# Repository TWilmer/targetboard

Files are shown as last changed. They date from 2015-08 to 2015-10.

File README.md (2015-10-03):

Targetboard

Warning1: v1 of the board has a bug in the VDD/VSS connection of the CAN drivers. To fix the board lift the power supply pins of the can transceiver chips
Warning2: v1 of the board has a bug in IR receiver footprint pin 1 and 3 are mixed up
Warning3: v1 of the board has the USB connector too near to the Serial Port

What works:
- IR sender
- Leds
- Button
- Serial Port 3
- WIFI port (no SW support yet)
- JTAG, I'm using a recent openocd on RPi B+

this is my hobby project. It supports a lot of features where I want me an my daughter to play with:
- Simulate a Traffic light
- USB to Serial communication
- USB to CAN-Bus (High-Speed only), you need a second board to make some use
- 4 motor drivers
- JTAG probe

The software part is released under GPL2 additionally you have to follow
the original Software's license - e.g. the firmware may be used only
for LPC parts. To compile you need also to install the LPCopen deliver for LPC1769 devices.

The CAD Files are released under GPL2, too. It contains a ZIP
file, which can be used to oder the PCB and if you want also assembly
from SeedStudio - including a proper BOM list.

http://www.seeedstudio.com/service/index.php?r=pcb

So far I have not received any Assembled PCB - so everything is at
your own risk.

This board will use a LPC1768 - as this is availble at SeedStudio, but a LPC1769 should work, too.  A higher clock frequency is possible with LPC1769, but I don't plan to use it.

A set of two assembled board cost around 140$, where you get 3 blank PCBs extra. As SeedStudio is assemblying manually - it should be possible to populate this board also manually.

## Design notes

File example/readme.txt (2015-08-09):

Based on the USB to UART bridge example

dfu-util -d 0x471:0xdf55 -c 0 -t 2048 -R -D /usr/local/lpcxpresso_7.5.0_254/lpcxpresso/bin/LPCXpressoWIN.enc
dfu-util -d 0x471:0xdf55 -c 0 -t 2048 -R -D  /usr/local/lpcxpresso_7.7.2_379/lpcxpresso/bin/LPCXpressoWIN.enc
This program is for the lpcexpresso Board. To be connected:

up to two can transceiver:
 - P0.4 and P0.5
 - P0.1 and P0.2
 
 one USB to Serial Converter at UART 0 - may also be used for intial programming i
  - P0.2 and P0.3 for programming P2.10 has to be low
  - P0.15 P0.16 as a connection to the Target
  
  We have up to 16 endpoints, this means we can make use of them:
   2 - UART to UART0
   2 - UART UART2 to Target
   2 - CAN0
   2 - CAN1

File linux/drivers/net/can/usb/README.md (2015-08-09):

CAN driver for LPC1769 Target board
================================================

Note
----
THIS SOFTWARE COMES WITHOUT ANY WARRANTY!

License
-------
GPL v2

How to build
------------
* Make sure you have kernel version >= 2.6.33 installed
* For pre-3.3 kernels, check out the pre-3.3 branch
* Install kernel header files and gcc
* Simple type "make"

DKMS integration
----------------
* Install the dkms package for your distro
* Check out the required branch from this repository
* Do a git archive --prefix=cantwi-1.0/ -o /usr/src/cantwi-1.0.tar HEAD
* Extract the archive in the /usr/src directory
* Add the module, e.g. with dkms add -m cantwi -v 1.0 --verbose
* Build the module, e.g. with dkms build -m cantwi -v 1.0 --verbose
* Install the module, e.g. with dkms install -m cantwi -v 1.0 --verbose
* You can also build packages for your distro, see man dkms

Set up interface
----------------
    modprobe can_raw
    modprobe can_dev
    insmod can_twi.ko
    ip link set can0 up type can bitrate 1000000 sample-point 0.875

Shut down interface
-------------------
    ip link set can0 down
    rmmod can_twi

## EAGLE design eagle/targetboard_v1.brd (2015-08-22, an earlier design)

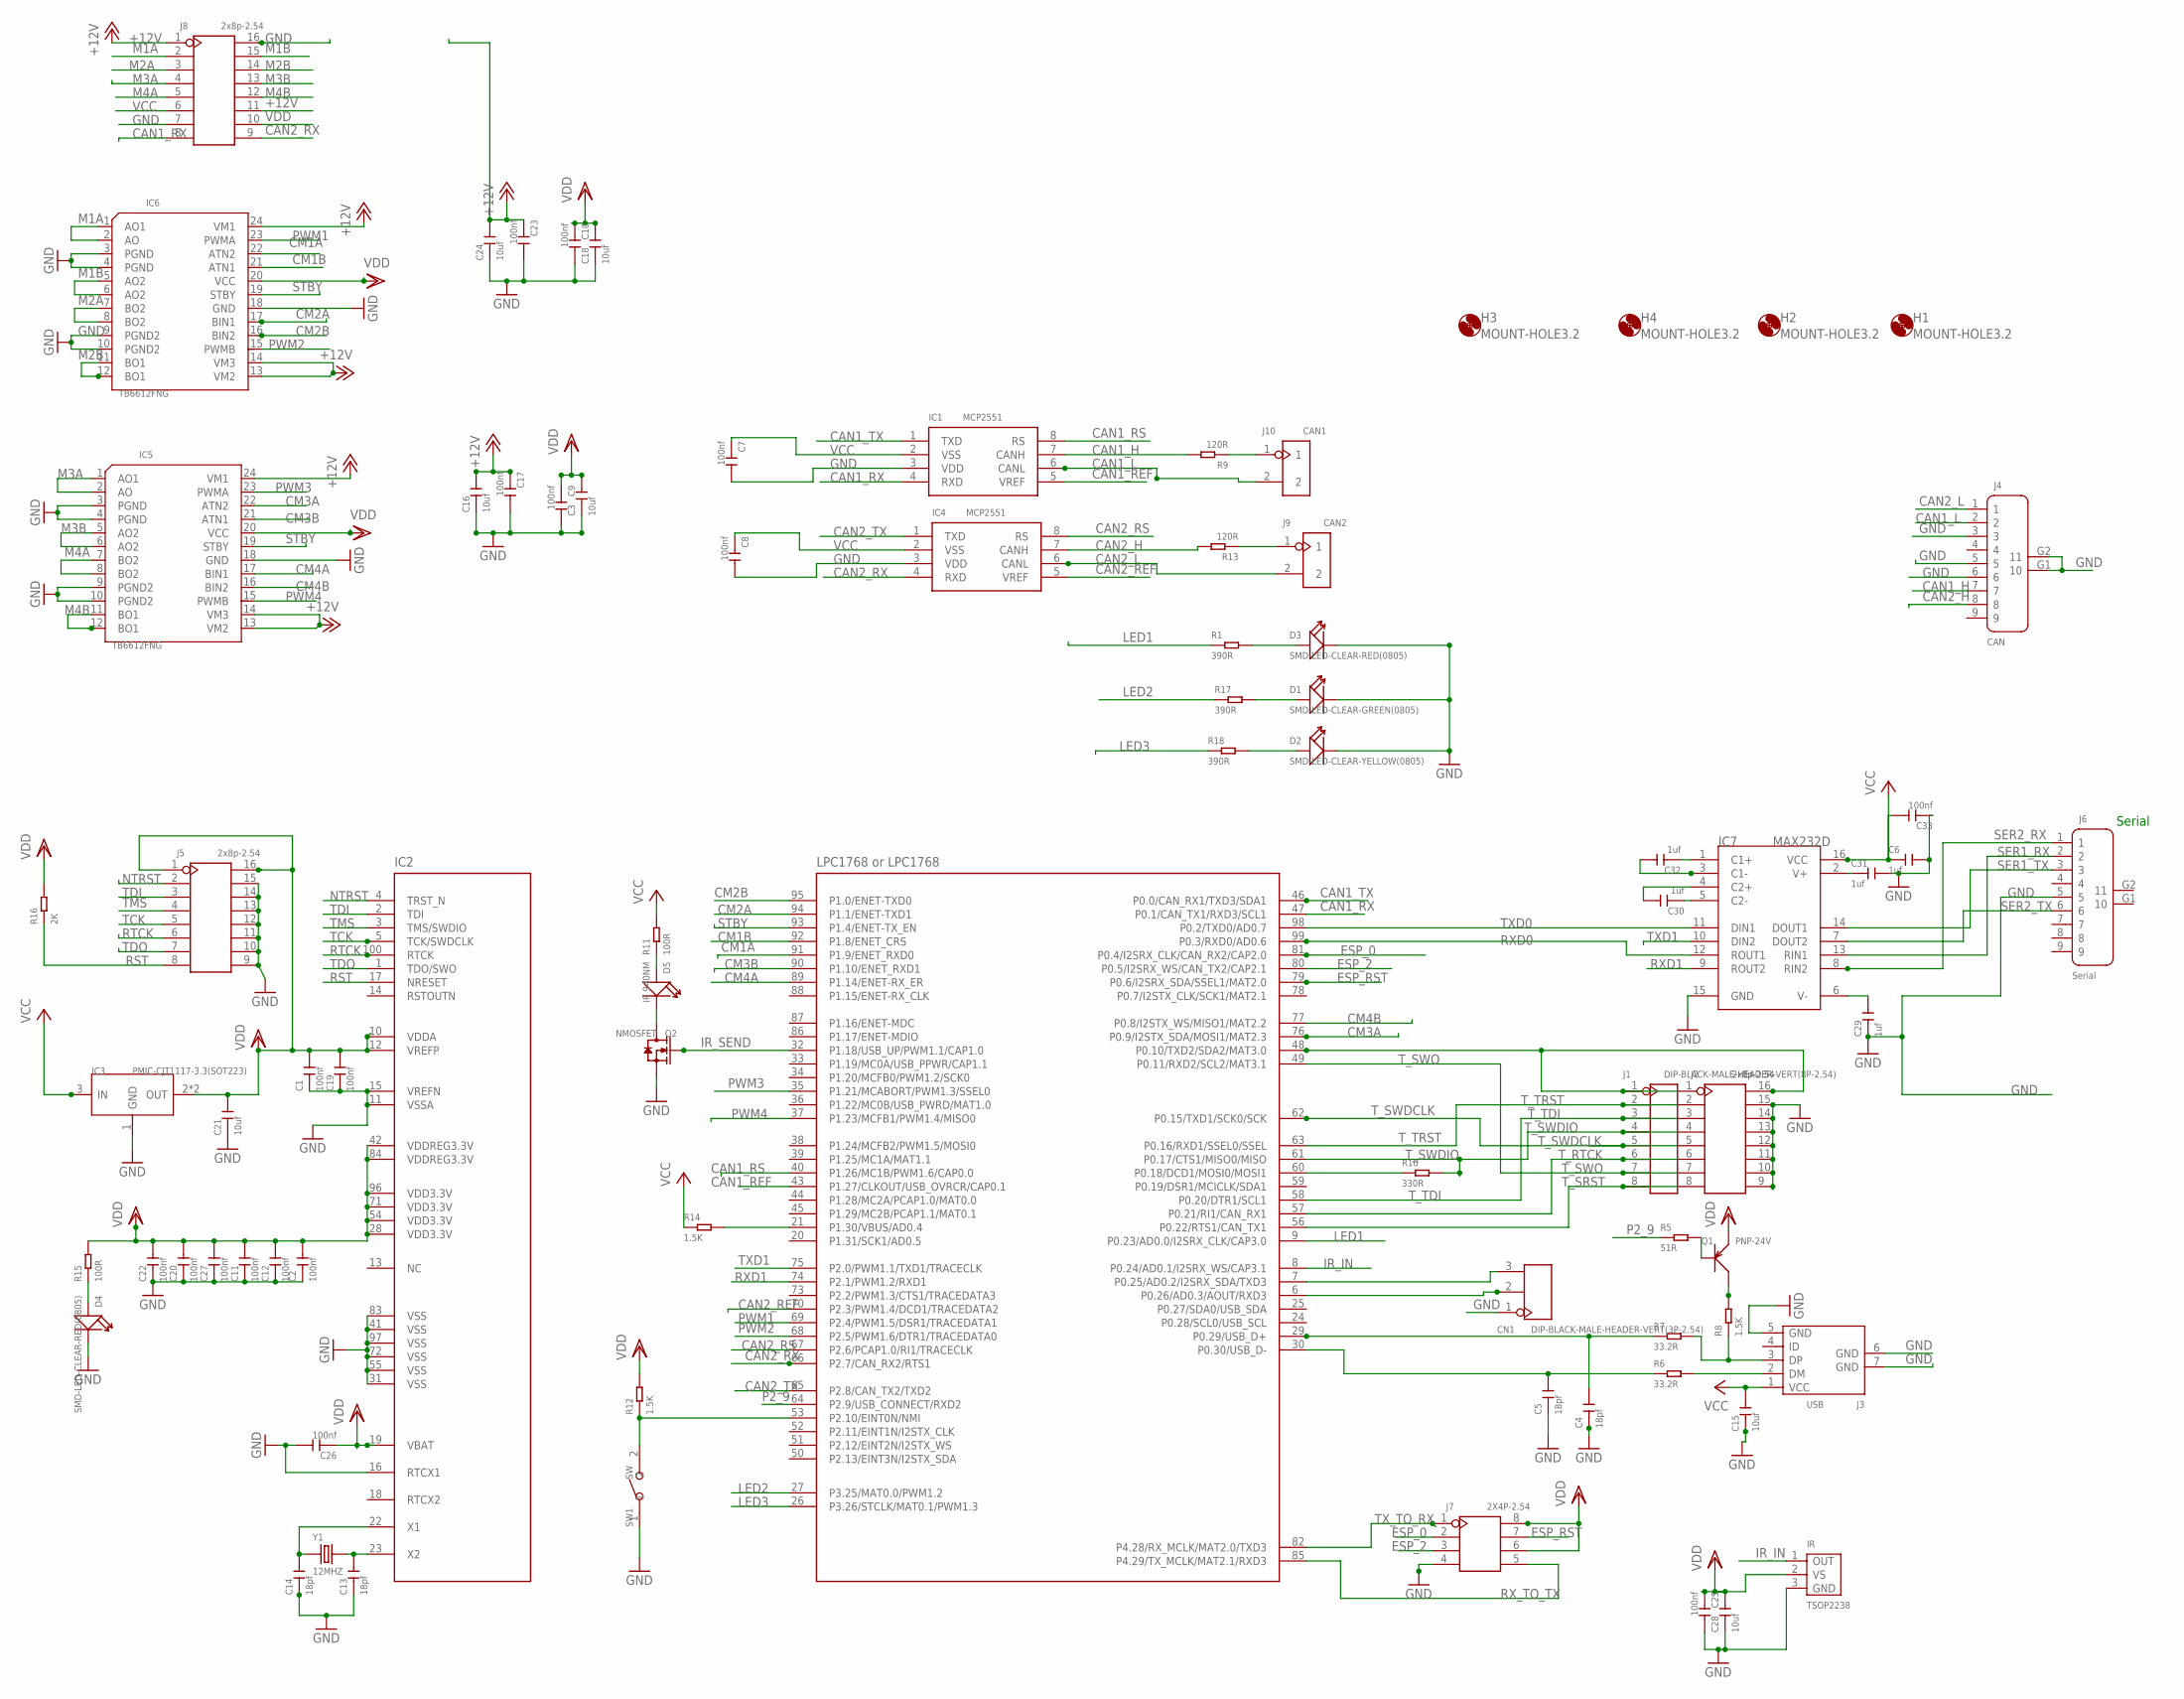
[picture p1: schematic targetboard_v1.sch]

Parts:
C1, C2, C7, C8, C9, C10, C11, C12, C17, C19, C20, C22, C23, C25, C26, C27, C33: 100nf; C0805
C3, C16, C18, C21, C24, C28: 10uf; C0805
C4, C5, C13, C14: 18pf; C0805
C6, C29, C30, C31, C32: 1uf; C0805
C15: 10uf; C0603
CN1: DIP-BLACK-MALE-HEADER-VERT(3P-2.54); H3-2.54
D1: SMD-LED-CLEAR-GREEN(0805); LED-0805
D2: SMD-LED-CLEAR-YELLOW(0805); LED-0805
D3, D4: SMD-LED-CLEAR-RED(0805); LED-0805
D5: IR 940NM; LED2-2.54-D5.0MM
H1, H2, H3, H4: MOUNT-HOLE3.2; 3,2
IC1, IC4: MCP2551; SOIC8-1.27-5X4MM
IC2: LPC1768 or LPC1768; LQFP100-0.5-13.8X13.8MM
IC3: PMIC-CJT1117-3.3(SOT223); SOT-223
IC5, IC6: TB6612FNG; SSOP24-0.65-8.9X5.3MM
IC7: MAX232D; SOIC16-1.27-10X3.9MM
IR: TSOP2238; SNR3-2.54-6.95X6.0X5.6MM
J1: DIP-BLACK-MALE-HEADER-VERT(8P-2.54); H8-2.54
J2, J5, J8: 2x8p-2.54; H2X8-2.54
J3: USB; MICRO-USB5+2P-SMD-0.65
J4: CAN; DSUB9+2P-2.77-90D-MALE
J6: Serial; DSUB9+2P-2.77-90D-MALE
J7: 2X4P-2.54; H2X4-2.54
J9: CAN2; H2-2.54
J10: CAN1; H2-2.54
Q1: PNP-24V; SOT-23
Q2: NMOSFET; SOT-23
R1, R17, R18: 390R; R0805
R5: 51R; R0603
R6, R7: 33.2R; R0603
R8, R12, R14: 1.5K; R0805
R9, R13: 120R; R0805
R10: 330R; R0603
R11, R15: 100R; R0805
R16: 2K; R0805
SW1: SW; SW2-2.6-3.0X2.5X1.2+0.4MM
Y1: 12MHZ; X2-SMD-5.0X3.2X1.3MM

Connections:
+12V: C16.2, C17.1, C23.1, C24.2, IC5.13 (VM2), IC5.14 (VM3), IC5.24 (VM1), IC6.13 (VM2), IC6.14 (VM3), IC6.24 (VM1), J8.1, J8.11
CAN1_H: IC1.7 (CANH), J4.7, R9.2
CAN1_L: IC1.6 (CANL), J4.2, J10.2
CAN1_REF: IC1.5 (VREF), IC2.43 (P1.27/CLKOUT/USB_OVRCR/CAP0.1)
CAN1_RS: IC1.8 (RS), IC2.40 (P1.26/MC1B/PWM1.6/CAP0.0)
CAN1_RX: IC1.4 (RXD), IC2.47 (P0.1/CAN_TX1/RXD3/SCL1), J8.8
CAN1_TX: IC1.1 (TXD), IC2.46 (P0.0/CAN_RX1/TXD3/SDA1)
CAN2_H: IC4.7 (CANH), J4.8, R13.2
CAN2_L: IC4.6 (CANL), J4.1, J9.2
CAN2_REF: IC2.70 (P2.3/PWM1.4/DCD1/TRACEDATA2), IC4.5 (VREF)
CAN2_RS: IC2.67 (P2.6/PCAP1.0/RI1/TRACECLK), IC4.8 (RS)
CAN2_RX: IC2.66 (P2.7/CAN_RX2/RTS1), IC4.4 (RXD), J8.9
CAN2_TX: IC2.65 (P2.8/CAN_TX2/TXD2), IC4.1 (TXD)
CM1A: IC2.91 (P1.9/ENET_RXD0), IC6.22 (ATN2)
CM1B: IC2.92 (P1.8/ENET_CRS), IC6.21 (ATN1)
CM2A: IC2.94 (P1.1/ENET-TXD1), IC6.17 (BIN1)
CM2B: IC2.95 (P1.0/ENET-TXD0), IC6.16 (BIN2)
CM3A: IC2.76 (P0.9/I2STX_SDA/MOSI1/MAT2.3), IC5.22 (ATN2)
CM3B: IC2.90 (P1.10/ENET_RXD1), IC5.21 (ATN1)
CM4A: IC2.89 (P1.14/ENET-RX_ER), IC5.17 (BIN1)
CM4B: IC2.77 (P0.8/I2STX_WS/MISO1/MAT2.2), IC5.16 (BIN2)
DM: J3.2 (DM), R6.2
DP: J3.3 (DP), R7.2, R8.1
EDM: C5.2, IC2.30 (P0.30/USB_D-), R6.1
EDP: C4.2, IC2.29 (P0.29/USB_D+), R7.1
ESP_0: IC2.81 (P0.4/I2SRX_CLK/CAN_RX2/CAP2.0), J7.2
ESP_2: IC2.80 (P0.5/I2SRX_WS/CAN_TX2/CAP2.1), J7.3
ESP_RST: IC2.79 (P0.6/I2SRX_SDA/SSEL1/MAT2.0), J7.7
GND: C1.1, C2.1, C3.1, C4.1, C5.1, C6.2, C7.2, C8.2, C9.2, C10.2, C11.1, C12.1, C13.1, C14.1, C15.1, C16.1, C17.2, C18.1, C19.1, C20.1, C21.1, C22.1, C23.2, C24.1, C25.2, C26.2, C27.1, C28.1, C29.1, C31.2, C33.1, CN1.1, D1.-, D2.-, D3.-, D4.-, IC1.3 (VDD), IC2.11 (VSSA), IC2.15 (VREFN), IC2.16 (RTCX1), IC2.31 (VSS), IC2.41 (VSS), IC2.55 (VSS), IC2.72 (VSS), IC2.83 (VSS), IC2.97 (VSS), IC3.1 (GND), IC4.3 (VDD), IC5.3 (PGND), IC5.4 (PGND), IC5.9 (PGND2), IC5.10 (PGND2), IC5.18 (GND), IC6.3 (PGND), IC6.4 (PGND), IC6.9 (PGND2), IC6.10 (PGND2), IC6.18 (GND), IC7.15 (GND), IR.3 (GND), J2.9, J2.10, J2.11, J2.12, J2.13, J2.14, J2.15, J3.5 (GND), J3.6 (GND), J3.7 (GND), J4.3, J4.5, J4.6, J4.G1 (10), J4.G2 (11), J5.9, J5.10, J5.11, J5.12, J5.13, J5.14, J5.15, J6.5, J7.4, J8.7, J8.16, Q2.2 (S), SW1.1
IR_IN: IC2.8 (P0.24/AD0.1/I2SRX_WS/CAP3.1), IR.1 (OUT)
IR_SEND: IC2.32 (P1.18/USB_UP/PWM1.1/CAP1.0), Q2.1 (G)
LED1: IC2.9 (P0.23/AD0.0/I2SRX_CLK/CAP3.0), R1.1
LED2: IC2.27 (P3.25/MAT0.0/PWM1.2), R17.1
LED3: IC2.26 (P3.26/STCLK/MAT0.1/PWM1.3), R18.1
M1A: IC6.1 (AO1), IC6.2 (AO), J8.2
M1B: IC6.5 (AO2), IC6.6 (AO2), J8.15
M2A: IC6.7 (BO2), IC6.8 (BO2), J8.3
M2B: IC6.11 (BO1), IC6.12 (BO1), J8.14
M3A: IC5.1 (AO1), IC5.2 (AO), J8.4
M3B: IC5.5 (AO2), IC5.6 (AO2), J8.13
M4A: IC5.7 (BO2), IC5.8 (BO2), J8.5
M4B: IC5.11 (BO1), IC5.12 (BO1), J8.12
unnamed: IC2.48 (P0.10/TXD2/SDA2/MAT3.0), J1.1, J2.1, J2.16
unnamed: IC2.53 (P2.10/EINT0N/NMI), R12.1, SW1.2
unnamed: D2.+, R18.2
unnamed: D1.+, R17.2
unnamed: D3.+, R1.2
unnamed: C14.2, IC2.22 (X1), Y1.1
unnamed: Q1.3 (C), R8.2
unnamed: C13.2, IC2.23 (X2), Y1.2
unnamed: Q1.1 (B), R5.2
unnamed: IC2.21 (P1.30/VBUS/AD0.4), R14.2
unnamed: J10.1, R9.1
unnamed: J9.1, R13.1
unnamed: D5.+, R11.1
unnamed: C30.2, IC7.4 (C2+)
unnamed: C30.1, IC7.5 (C2-)
unnamed: C32.1, IC7.1 (C1+)
unnamed: C32.2, IC7.3 (C1-)
unnamed: C29.2, IC7.6 (V-)
unnamed: C31.1, IC7.2 (V+)
unnamed: D5.-, Q2.3 (D)
unnamed: IC2.60 (P0.18/DCD1/MOSI0/MOSI1), R10.1
unnamed: D4.+, R15.1
NTRST: IC2.4 (TRST_N), J5.2
P2_9: IC2.64 (P2.9/USB_CONNECT/RXD2), R5.1
PWM1: IC2.69 (P2.4/PWM1.5/DSR1/TRACEDATA1), IC6.23 (PWMA)
PWM2: IC2.68 (P2.5/PWM1.6/DTR1/TRACEDATA0), IC6.15 (PWMB)
PWM3: IC2.35 (P1.21/MCABORT/PWM1.3/SSEL0), IC5.23 (PWMA)
PWM4: IC2.37 (P1.23/MCFB1/PWM1.4/MISO0), IC5.15 (PWMB)
RST: IC2.17 (NRESET), J5.8, R16.1
RTCK: IC2.100 (RTCK), J5.6
RX3: CN1.2, IC2.6 (P0.26/AD0.3/AOUT/RXD3)
RXD0: IC2.99 (P0.3/RXD0/AD0.6), IC7.12 (ROUT1)
RXD1: IC2.74 (P2.1/PWM1.2/RXD1), IC7.9 (ROUT2)
RX_TO_TX: IC2.85 (P4.29/TX_MCLK/MAT2.1/RXD3), J7.5
SER1_RX: IC7.13 (RIN1), J6.2
SER1_TX: IC7.14 (DOUT1), J6.3
SER2_RX: IC7.8 (RIN2), J6.1
SER2_TX: IC7.7 (DOUT2), J6.6
STBY: IC2.93 (P1.4/ENET-TX_EN), IC5.19 (STBY), IC6.19 (STBY)
TCK: IC2.5 (TCK/SWDCLK), J5.5
TDI: IC2.2 (TDI), J5.3
TDO: IC2.1 (TDO/SWO), J5.7
TMS: IC2.3 (TMS/SWDIO), J5.4
TX3: CN1.3, IC2.7 (P0.25/AD0.2/I2SRX_SDA/TXD3)
TXD0: IC2.98 (P0.2/TXD0/AD0.7), IC7.11 (DIN1)
TXD1: IC2.75 (P2.0/PWM1.1/TXD1/TRACECLK), IC7.10 (DIN2)
TX_TO_RX: IC2.82 (P4.28/RX_MCLK/MAT2.0/TXD3), J7.1
T_RTCK: IC2.57 (P0.21/RI1/CAN_RX1), J1.6, J2.6
T_SRST: IC2.56 (P0.22/RTS1/CAN_TX1), J1.8, J2.8
T_SWDCLK: IC2.62 (P0.15/TXD1/SCK0/SCK), J1.5, J2.5
T_SWDIO: IC2.61 (P0.17/CTS1/MISO0/MISO), J1.4, J2.4, R10.2
T_SWO: IC2.49 (P0.11/RXD2/SCL2/MAT3.1), J1.7, J2.7
T_TDI: IC2.58 (P0.20/DTR1/SCL1), J1.3, J2.3
T_TRST: IC2.63 (P0.16/RXD1/SSEL0/SSEL), J1.2, J2.2
VCC: C6.1, C7.1, C8.1, C15.2, C33.2, IC1.2 (VSS), IC3.3 (IN), IC4.2 (VSS), IC7.16 (VCC), J3.1 (VCC), J8.6, R11.2, R14.1
VDD: C1.2, C2.2, C3.2, C9.1, C10.1, C11.2, C12.2, C18.2, C19.2, C20.2, C21.2, C22.2, C25.1, C26.1, C27.2, C28.2, IC2.10 (VDDA), IC2.12 (VREFP), IC2.19 (VBAT), IC2.28 (VDD3.3V), IC2.42 (VDDREG3.3V), IC2.54 (VDD3.3V), IC2.71 (VDD3.3V), IC2.84 (VDDREG3.3V), IC2.96 (VDD3.3V), IC3.2 (OUT), IC3.TER (OUT), IC5.20 (VCC), IC6.20 (VCC), IR.2 (VS), J5.1, J5.16, J7.6, J7.8, J8.10, Q1.2 (E), R12.2, R15.2, R16.2

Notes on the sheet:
Serial

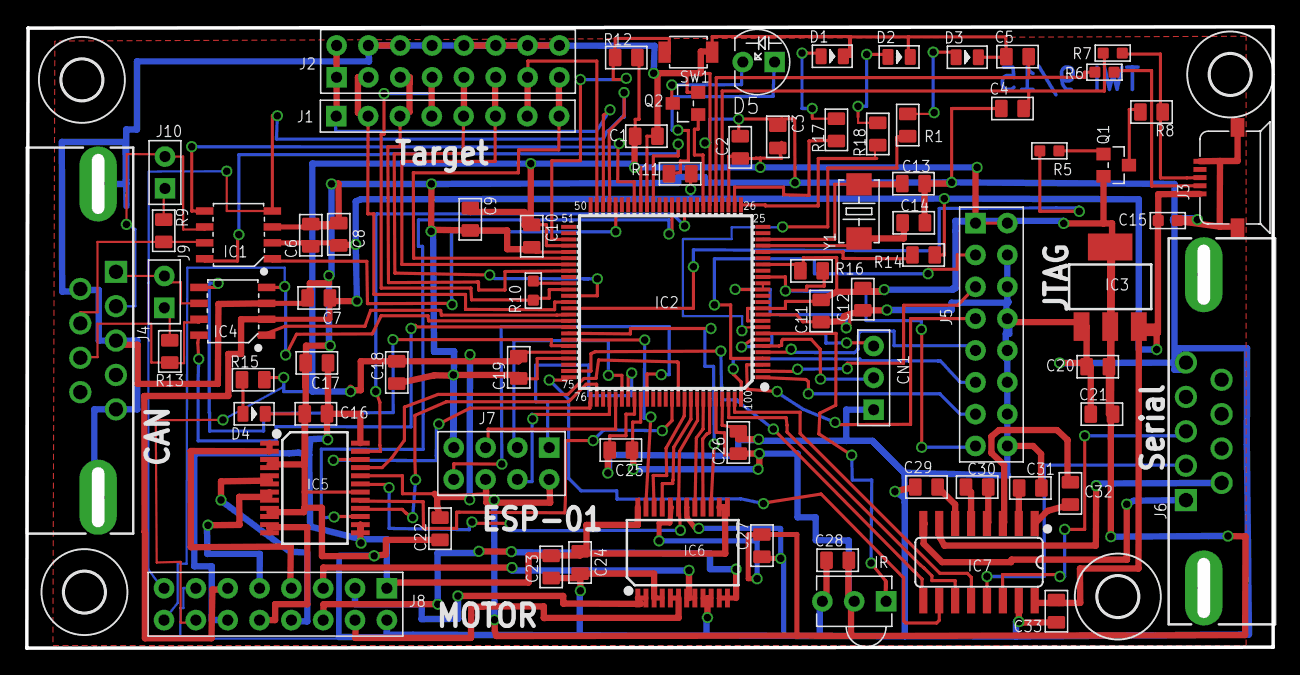
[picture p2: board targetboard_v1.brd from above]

Board: 2 copper layers, 99.4 x 49.6 mm, 80 parts (0 on the bottom side), 98 nets.

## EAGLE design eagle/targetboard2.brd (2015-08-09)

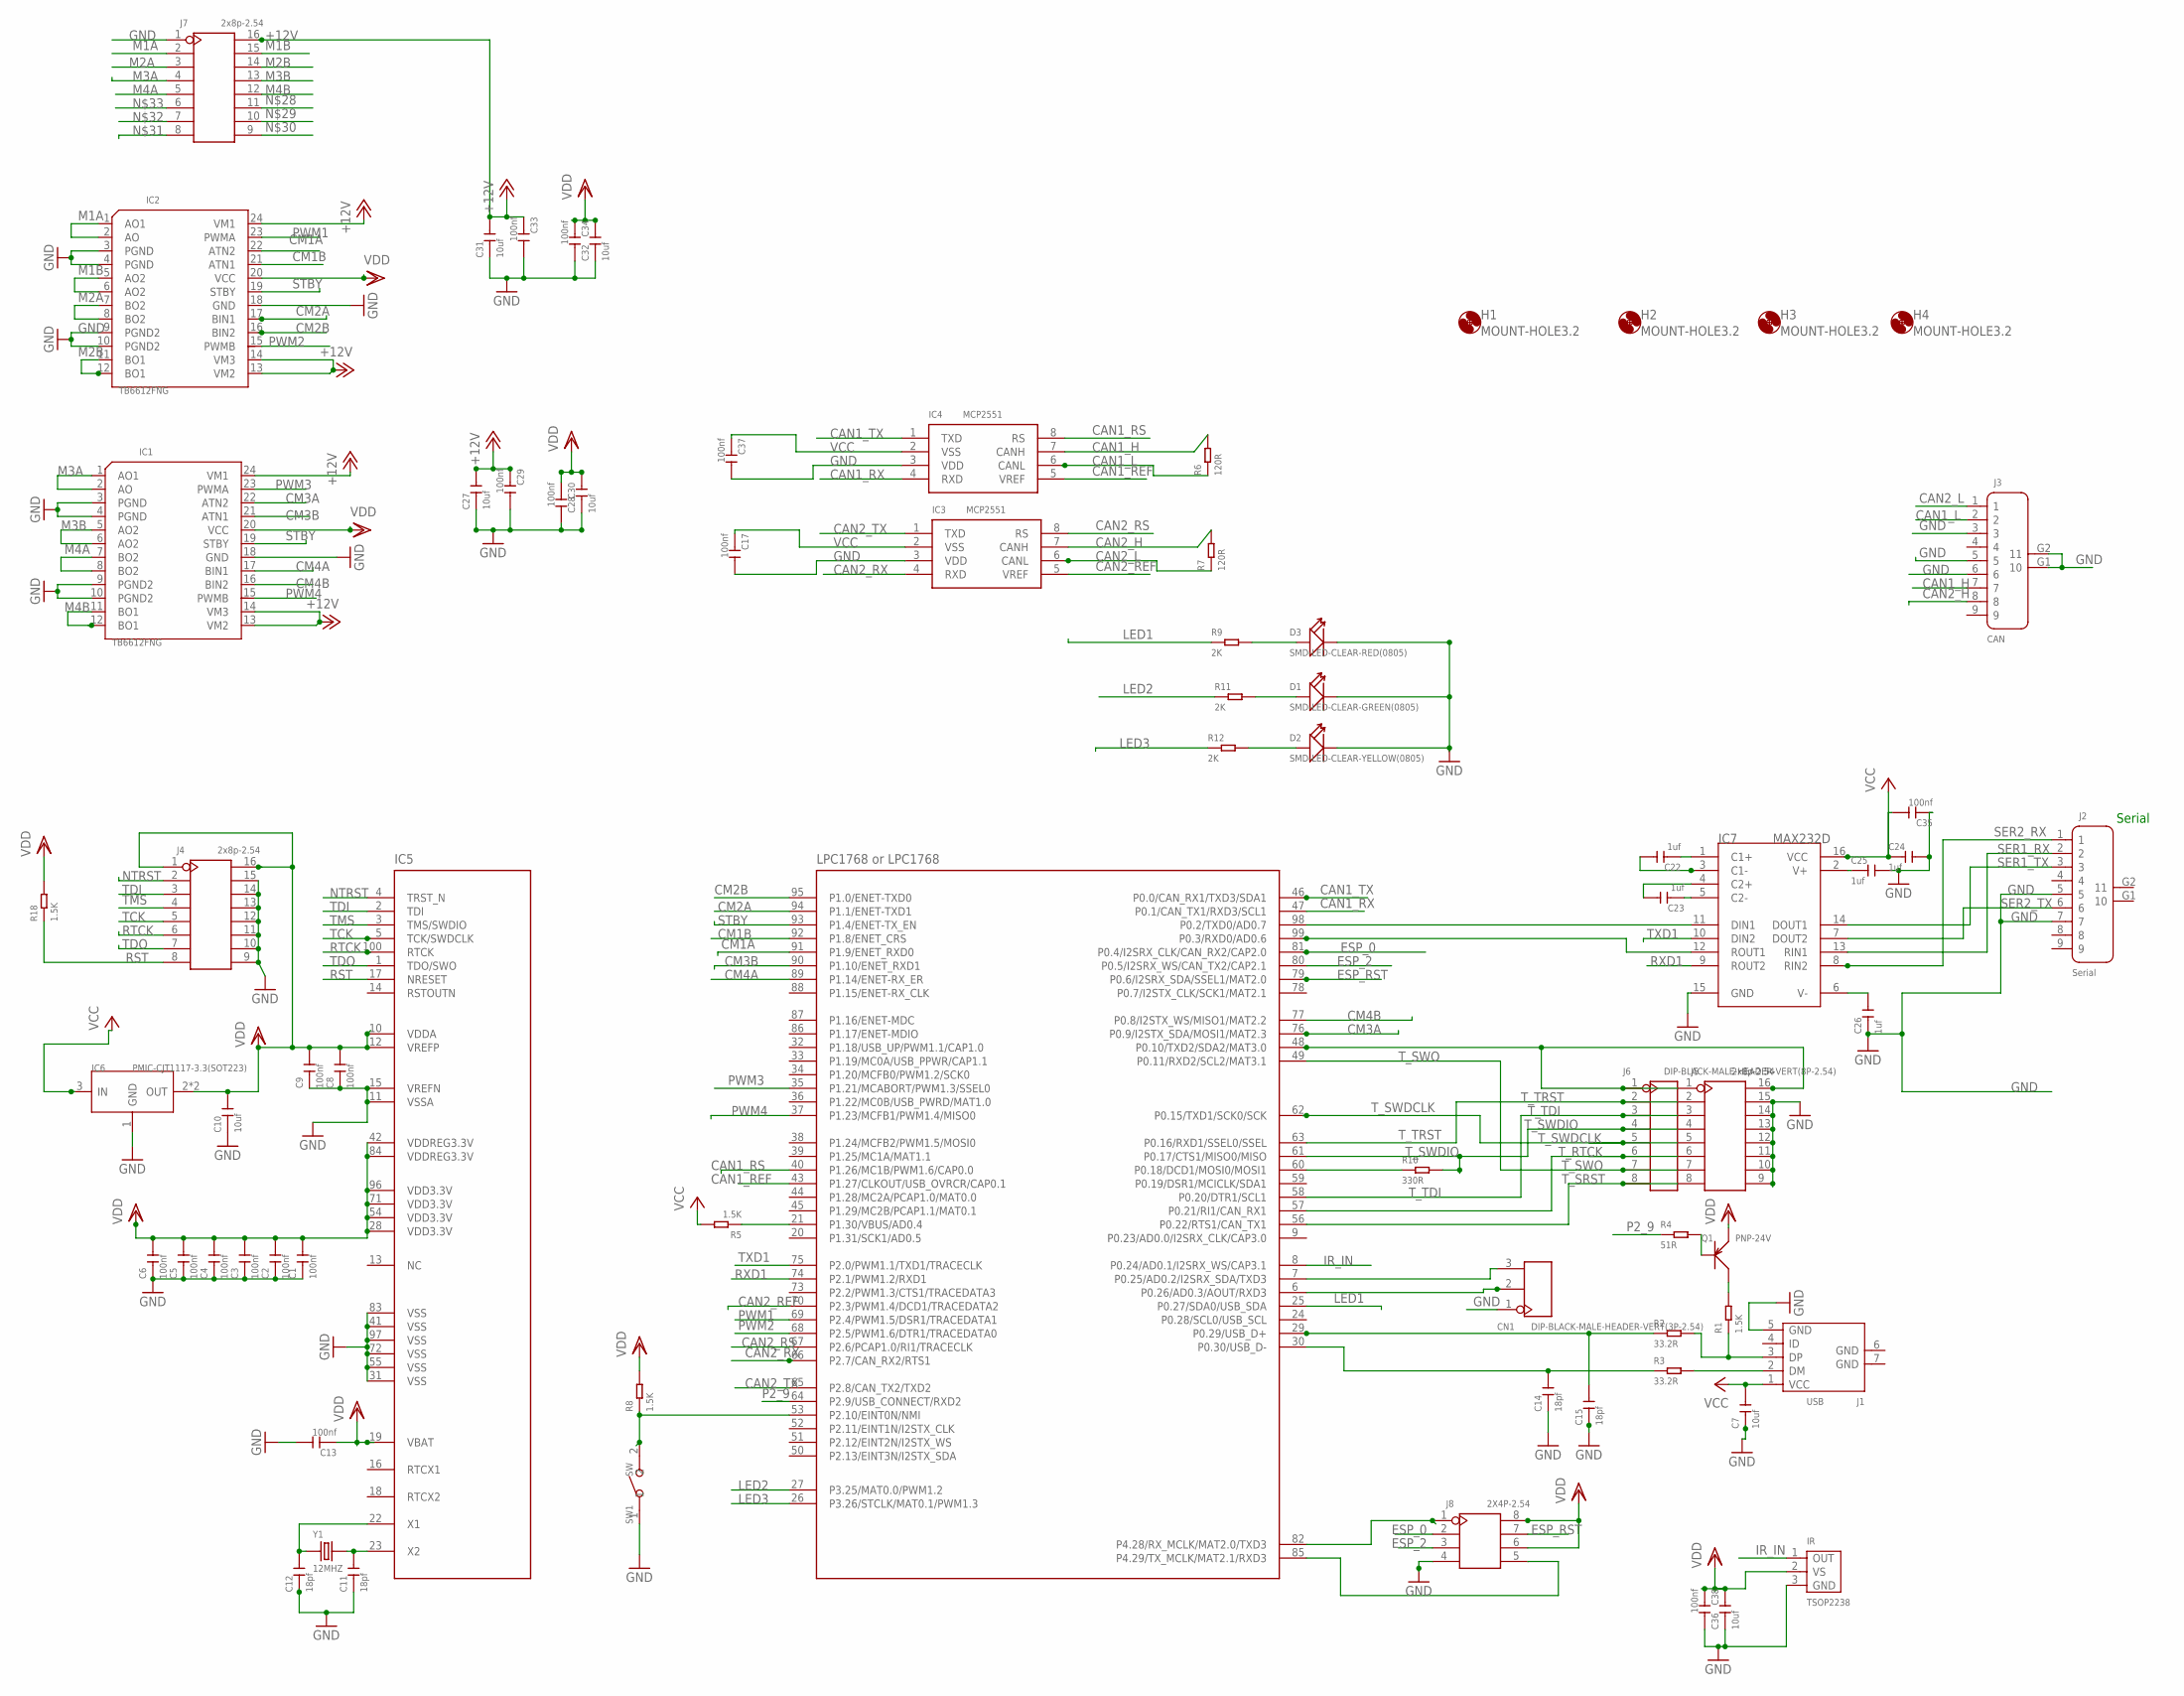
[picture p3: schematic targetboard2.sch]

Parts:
C1, C2, C3, C4, C5, C6, C8, C9, C13, C17, C29, C30, C33, C34, C35, C37, C38: 100nf; C0805
C7: 10uf; C0603
C10, C27, C28, C31, C32, C36: 10uf; C0805
C11, C12, C14, C15: 18pf; C0805
C22, C23, C24, C25, C26: 1uf; C0805
CN1: DIP-BLACK-MALE-HEADER-VERT(3P-2.54); H3-2.54
D1: SMD-LED-CLEAR-GREEN(0805); LED-0805
D2: SMD-LED-CLEAR-YELLOW(0805); LED-0805
D3: SMD-LED-CLEAR-RED(0805); LED-0805
H1, H2, H3, H4: MOUNT-HOLE3.2; 3,2
IC1, IC2: TB6612FNG; SSOP24-0.65-8.9X5.3MM
IC3, IC4: MCP2551; SOIC8-1.27-5X4MM
IC5: LPC1768 or LPC1768; LQFP100-0.5-13.8X13.8MM
IC6: PMIC-CJT1117-3.3(SOT223); SOT-223
IC7: MAX232D; SOIC16-1.27-10X3.9MM
IR: TSOP2238; SNR3-2.54-6.95X6.0X5.6MM
J1: USB; MICRO-USB5+2P-SMD-0.65
J2: Serial; DSUB9+2P-2.77-90D-MALE
J3: CAN; DSUB9+2P-2.77-90D-MALE
J4, J5, J7: 2x8p-2.54; H2X8-2.54
J6: DIP-BLACK-MALE-HEADER-VERT(8P-2.54); H8-2.54
J8: 2X4P-2.54; H2X4-2.54
Q1: PNP-24V; SOT-23
R1, R5, R8, R18: 1.5K; R0402
R2, R3: 33.2R; R0603
R4: 51R; R0603
R6, R7: 120R; R0805
R9, R11, R12: 2K; R0805
R10: 330R; R0603
SW1: SW; SW2-2.6-3.0X2.5X1.2+0.4MM
Y1: 12MHZ; X2-SMD-5.0X3.2X1.3MM

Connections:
+12V: C27.2, C29.1, C31.2, C33.1, IC1.13 (VM2), IC1.14 (VM3), IC1.24 (VM1), IC2.13 (VM2), IC2.14 (VM3), IC2.24 (VM1), J7.16
CAN1_H: IC4.7 (CANH), J3.7, R6.2
CAN1_L: IC4.6 (CANL), J3.2, R6.1
CAN1_REF: IC4.5 (VREF), IC5.43 (P1.27/CLKOUT/USB_OVRCR/CAP0.1)
CAN1_RS: IC4.8 (RS), IC5.40 (P1.26/MC1B/PWM1.6/CAP0.0)
CAN1_RX: IC4.4 (RXD), IC5.47 (P0.1/CAN_TX1/RXD3/SCL1)
CAN1_TX: IC4.1 (TXD), IC5.46 (P0.0/CAN_RX1/TXD3/SDA1)
CAN2_H: IC3.7 (CANH), J3.8, R7.2
CAN2_L: IC3.6 (CANL), J3.1, R7.1
CAN2_REF: IC3.5 (VREF), IC5.70 (P2.3/PWM1.4/DCD1/TRACEDATA2)
CAN2_RS: IC3.8 (RS), IC5.67 (P2.6/PCAP1.0/RI1/TRACECLK)
CAN2_RX: IC3.4 (RXD), IC5.66 (P2.7/CAN_RX2/RTS1)
CAN2_TX: IC3.1 (TXD), IC5.65 (P2.8/CAN_TX2/TXD2)
CM1A: IC2.22 (ATN2), IC5.91 (P1.9/ENET_RXD0)
CM1B: IC2.21 (ATN1), IC5.92 (P1.8/ENET_CRS)
CM2A: IC2.17 (BIN1), IC5.94 (P1.1/ENET-TXD1)
CM2B: IC2.16 (BIN2), IC5.95 (P1.0/ENET-TXD0)
CM3A: IC1.22 (ATN2), IC5.76 (P0.9/I2STX_SDA/MOSI1/MAT2.3)
CM3B: IC1.21 (ATN1), IC5.90 (P1.10/ENET_RXD1)
CM4A: IC1.17 (BIN1), IC5.89 (P1.14/ENET-RX_ER)
CM4B: IC1.16 (BIN2), IC5.77 (P0.8/I2STX_WS/MISO1/MAT2.2)
DM: J1.2 (DM), R3.2
DP: J1.3 (DP), R1.1, R2.2
EDM: C14.2, IC5.30 (P0.30/USB_D-), R3.1
EDP: C15.2, IC5.29 (P0.29/USB_D+), R2.1
ESP_0: IC5.81 (P0.4/I2SRX_CLK/CAN_RX2/CAP2.0), J8.2
ESP_2: IC5.80 (P0.5/I2SRX_WS/CAN_TX2/CAP2.1), J8.3
ESP_RST: IC5.79 (P0.6/I2SRX_SDA/SSEL1/MAT2.0), J8.7
GND: C1.1, C2.1, C3.1, C4.1, C5.1, C6.1, C7.1, C8.1, C9.1, C10.1, C11.1, C12.1, C13.2, C14.1, C15.1, C17.2, C24.2, C25.2, C26.1, C27.1, C28.1, C29.2, C30.2, C31.1, C32.1, C33.2, C34.2, C35.1, C36.1, C37.2, C38.2, CN1.1, D1.-, D2.-, D3.-, IC1.3 (PGND), IC1.4 (PGND), IC1.9 (PGND2), IC1.10 (PGND2), IC1.18 (GND), IC2.3 (PGND), IC2.4 (PGND), IC2.9 (PGND2), IC2.10 (PGND2), IC2.18 (GND), IC3.3 (VDD), IC4.3 (VDD), IC5.11 (VSSA), IC5.15 (VREFN), IC5.31 (VSS), IC5.41 (VSS), IC5.55 (VSS), IC5.72 (VSS), IC5.83 (VSS), IC5.97 (VSS), IC6.1 (GND), IC7.15 (GND), IR.3 (GND), J1.5 (GND), J2.5, J2.7, J3.3, J3.5, J3.6, J3.G1 (10), J3.G2 (11), J4.9, J4.10, J4.11, J4.12, J4.13, J4.14, J4.15, J5.9, J5.10, J5.11, J5.12, J5.13, J5.14, J5.15, J7.1, J8.4, SW1.1
IR_IN: IC5.8 (P0.24/AD0.1/I2SRX_WS/CAP3.1), IR.1 (OUT)
LED1: IC5.25 (P0.27/SDA0/USB_SDA), R9.1
LED2: IC5.27 (P3.25/MAT0.0/PWM1.2), R11.1
LED3: IC5.26 (P3.26/STCLK/MAT0.1/PWM1.3), R12.1
M1A: IC2.1 (AO1), IC2.2 (AO), J7.2
M1B: IC2.5 (AO2), IC2.6 (AO2), J7.15
M2A: IC2.7 (BO2), IC2.8 (BO2), J7.3
M2B: IC2.11 (BO1), IC2.12 (BO1), J7.14
M3A: IC1.1 (AO1), IC1.2 (AO), J7.4
M3B: IC1.5 (AO2), IC1.6 (AO2), J7.13
M4A: IC1.7 (BO2), IC1.8 (BO2), J7.5
M4B: IC1.11 (BO1), IC1.12 (BO1), J7.12
unnamed: IC5.48 (P0.10/TXD2/SDA2/MAT3.0), J5.1, J5.16, J6.1
unnamed: IC5.53 (P2.10/EINT0N/NMI), R8.1, SW1.2
unnamed: D2.+, R12.2
unnamed: D1.+, R11.2
unnamed: D3.+, R9.2
unnamed: C12.2, IC5.22 (X1), Y1.1
unnamed: Q1.3 (C), R1.2
unnamed: C11.2, IC5.23 (X2), Y1.2
unnamed: Q1.1 (B), R4.2
unnamed: IC5.21 (P1.30/VBUS/AD0.4), R5.1
unnamed: IC5.85 (P4.29/TX_MCLK/MAT2.1/RXD3), J8.5
unnamed: IC5.98 (P0.2/TXD0/AD0.7), IC7.11 (DIN1)
unnamed: IC5.99 (P0.3/RXD0/AD0.6), IC7.12 (ROUT1)
unnamed: C23.2, IC7.4 (C2+)
unnamed: C23.1, IC7.5 (C2-)
unnamed: C22.1, IC7.1 (C1+)
unnamed: C22.2, IC7.3 (C1-)
unnamed: C26.2, IC7.6 (V-)
unnamed: C25.1, IC7.2 (V+)
unnamed: IC5.60 (P0.18/DCD1/MOSI0/MOSI1), R10.1
unnamed: IC5.82 (P4.28/RX_MCLK/MAT2.0/TXD3), J8.1
NTRST: IC5.4 (TRST_N), J4.2
P2_9: IC5.64 (P2.9/USB_CONNECT/RXD2), R4.1
PWM1: IC2.23 (PWMA), IC5.69 (P2.4/PWM1.5/DSR1/TRACEDATA1)
PWM2: IC2.15 (PWMB), IC5.68 (P2.5/PWM1.6/DTR1/TRACEDATA0)
PWM3: IC1.23 (PWMA), IC5.35 (P1.21/MCABORT/PWM1.3/SSEL0)
PWM4: IC1.15 (PWMB), IC5.37 (P1.23/MCFB1/PWM1.4/MISO0)
RST: IC5.17 (NRESET), J4.8, R18.1
RTCK: IC5.100 (RTCK), J4.6
RX3: CN1.2, IC5.6 (P0.26/AD0.3/AOUT/RXD3)
RXD1: IC5.74 (P2.1/PWM1.2/RXD1), IC7.9 (ROUT2)
SER1_RX: IC7.13 (RIN1), J2.2
SER1_TX: IC7.14 (DOUT1), J2.3
SER2_RX: IC7.8 (RIN2), J2.1
SER2_TX: IC7.7 (DOUT2), J2.6
STBY: IC1.19 (STBY), IC2.19 (STBY), IC5.93 (P1.4/ENET-TX_EN)
TCK: IC5.5 (TCK/SWDCLK), J4.5
TDI: IC5.2 (TDI), J4.3
TDO: IC5.1 (TDO/SWO), J4.7
TMS: IC5.3 (TMS/SWDIO), J4.4
TX3: CN1.3, IC5.7 (P0.25/AD0.2/I2SRX_SDA/TXD3)
TXD1: IC5.75 (P2.0/PWM1.1/TXD1/TRACECLK), IC7.10 (DIN2)
T_RTCK: IC5.57 (P0.21/RI1/CAN_RX1), J5.6, J6.6
T_SRST: IC5.56 (P0.22/RTS1/CAN_TX1), J5.8, J6.8
T_SWDCLK: IC5.62 (P0.15/TXD1/SCK0/SCK), J5.5, J6.5
T_SWDIO: IC5.61 (P0.17/CTS1/MISO0/MISO), J5.4, J6.4, R10.2
T_SWO: IC5.49 (P0.11/RXD2/SCL2/MAT3.1), J5.7, J6.7
T_TDI: IC5.58 (P0.20/DTR1/SCL1), J5.3, J6.3
T_TRST: IC5.63 (P0.16/RXD1/SSEL0/SSEL), J5.2, J6.2
VCC: C7.2, C17.1, C24.1, C35.2, C37.1, IC3.2 (VSS), IC4.2 (VSS), IC6.3 (IN), IC7.16 (VCC), J1.1 (VCC), R5.2
VDD: C1.2, C2.2, C3.2, C4.2, C5.2, C6.2, C8.2, C9.2, C10.2, C13.1, C28.2, C30.1, C32.2, C34.1, C36.2, C38.1, IC1.20 (VCC), IC2.20 (VCC), IC5.10 (VDDA), IC5.12 (VREFP), IC5.19 (VBAT), IC5.28 (VDD3.3V), IC5.42 (VDDREG3.3V), IC5.54 (VDD3.3V), IC5.71 (VDD3.3V), IC5.84 (VDDREG3.3V), IC5.96 (VDD3.3V), IC6.2 (OUT), IC6.TER (OUT), IR.2 (VS), J4.1, J4.16, J8.6, J8.8, Q1.2 (E), R8.2, R18.2

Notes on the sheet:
Serial

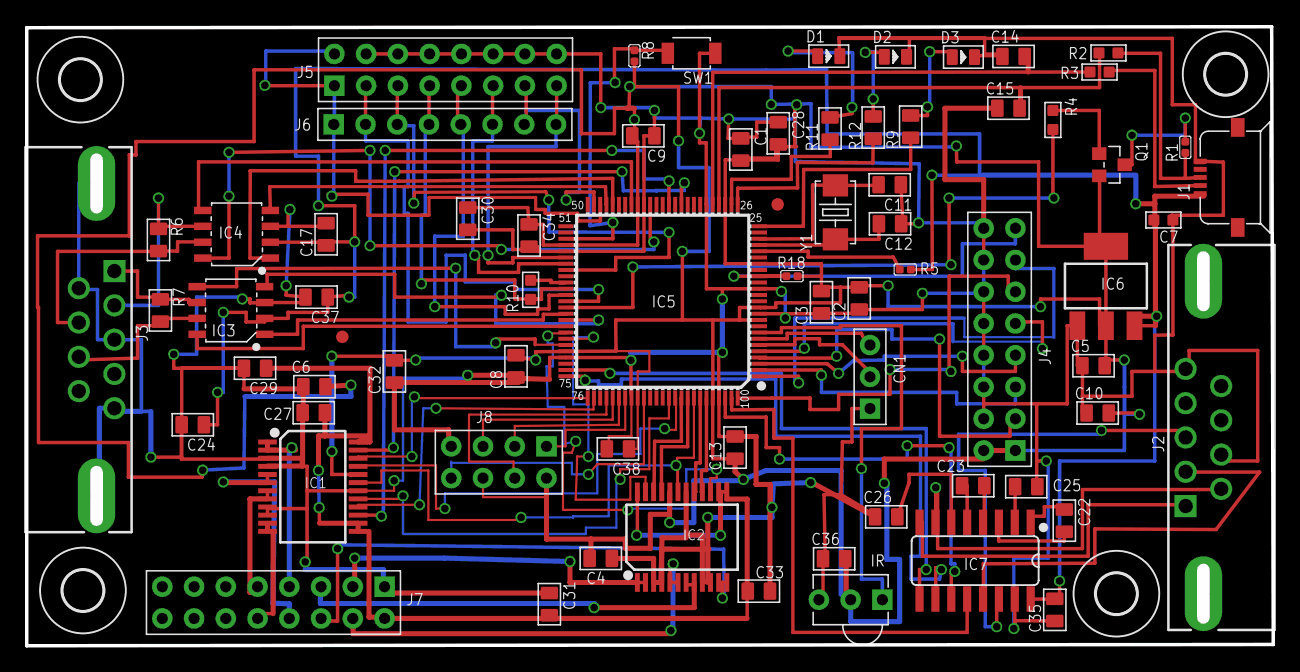
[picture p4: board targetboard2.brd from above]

Board: 2 copper layers, 99.7 x 49.5 mm, 75 parts (0 on the bottom side), 92 nets.

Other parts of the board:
U$4, U$5: FIDUCIAL_G10

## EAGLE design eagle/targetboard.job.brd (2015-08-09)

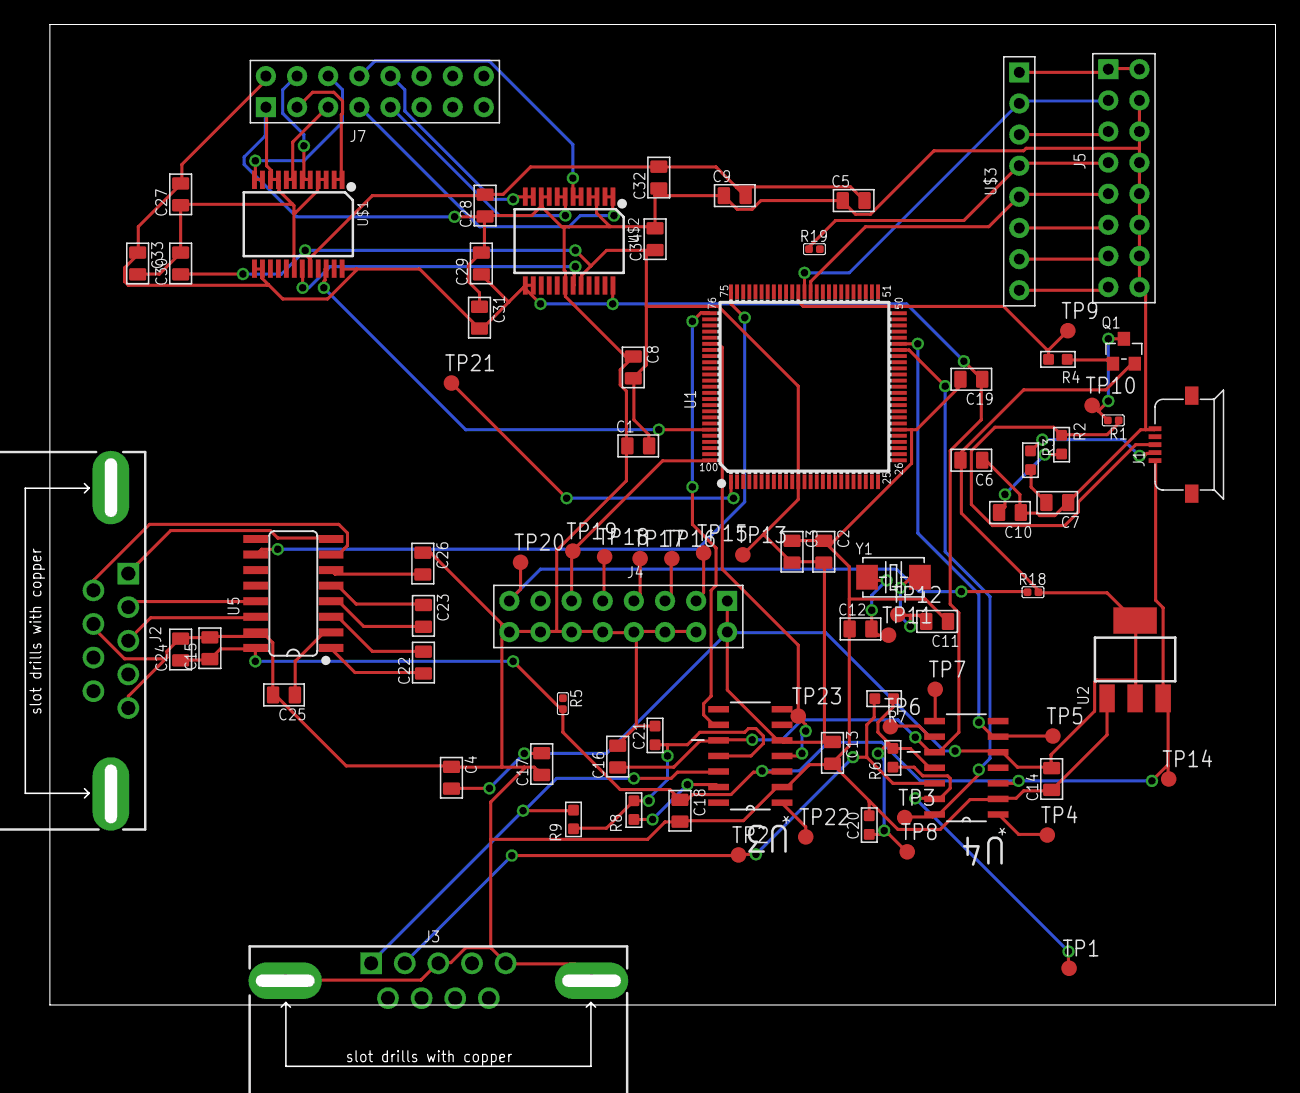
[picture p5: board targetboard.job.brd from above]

Board: 2 copper layers, 102.0 x 85.0 mm, 84 parts (0 on the bottom side), 77 nets.

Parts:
C1, C2, C3, C4, C5, C6, C8, C9, C13, C14, C15, C16, C17, C18, C19, C29, C30, C33, C34: 100nf; C0805
C7, C10, C11, C12: 18pf; C0805
C20, C21: 22nf; C0603
C22, C23, C24, C25, C26: 1uf; C0805
C27, C28, C31, C32: 10uf; C0805
J1: MICRO-USB5+2P-SMD-0.65
J2, J3: DSUB9+2P-2.77-90D-MALE
J4, J5, J7: 2x8p-2.54; H2X8-2.54
Q1: SOT-23
R1, R5, R18, R19: 1.5K; R0402
R2, R3: 33.2R; R0603
R4: 51R; R0603
R6, R7, R8, R9: 56.2R; R0603
TP1, TP2, TP3, TP4, TP5, TP6, TP7, TP8, TP9, TP10, TP11, TP12, TP13, TP14, TP15, TP16, TP17, TP18, TP19, TP20, TP21, TP22, TP23: TPB1,27; B1,27
U1: LQFP100-0.5-13.8X13.8MM
U2: PMIC-CJT1117-3.3(SOT223); SOT-223
U3, U4: TJA1041AT; SOIC127P600X175-14N
U5: SOIC16-1.27-10X3.9MM
U$1, U$2: SSOP24-0.65-8.9X5.3MM
U$3: DIP-BLACK-MALE-HEADER-VERT(8P-2.54); H8-2.54
Y1: 12MHZ; X2-SMD-5.0X3.2X1.3MM

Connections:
+12V: C16.1, C19.1, C27.2, C29.1, C31.2, C33.1, J7.16, U3.10, U4.10, U$1.13, U$1.14, U$1.24, U$2.13, U$2.14, U$2.24
CAN1_EN: TP5.TP, U1.45, U4.6
CAN1_ERR: TP7.TP, U1.43, U4.8
CAN1_H: J3.7, R6.2, TP1.TP, U4.13
CAN1_L: J3.2, R7.1, TP2.TP, U4.12
CAN1_RX: U1.47, U4.4
CAN1_STB: TP3.TP, U1.44, U4.14
CAN1_TX: TP4.TP, U1.46, U4.1
CAN1_WAKE: TP6.TP, U1.40, U4.9
CAN2_EN: U1.78, U3.6
CAN2_ERR: U1.77, U3.8
CAN2_H: J3.8, R8.2, U3.13
CAN2_L: J3.1, R9.1, U3.12
CAN2_RX: TP23.TP, U1.81, U3.4
CAN2_STB: U1.79, U3.14
CAN2_TX: TP22.TP, U1.80, U3.1
CAN2_WAKE: U1.76, U3.9
CM1A: U1.95, U$1.22
CM3A: U1.91, U$2.22
GND: C1.1, C2.1, C3.1, C4.1, C5.1, C6.1, C7.1, C8.1, C9.1, C10.1, C11.1, C12.1, C13.2, C14.1, C15.2, C16.2, C17.1, C18.2, C19.2, C20.2, C21.2, C24.2, C25.2, C26.1, C27.1, C28.1, C29.2, C30.2, C31.1, C32.1, C33.2, C34.2, J1.5, J2.5, J2.7, J3.3, J3.5, J3.6, J3.G1, J3.G2, J4.9, J4.10, J4.11, J4.12, J4.13, J4.14, J4.15, J5.9, J5.10, J5.11, J5.12, J5.13, J5.14, J5.15, J7.1, U1.11, U1.15, U1.31, U1.41, U1.55, U1.72, U1.83, U1.97, U2.1, U3.2, U4.2, U5.15, U$1.3, U$1.4, U$1.9, U$1.10, U$1.18, U$2.3, U$2.4, U$2.9, U$2.10, U$2.18
M1A: J7.2, U$1.1, U$1.2
M1B: J7.15, U$1.5, U$1.6
M2A: J7.3, U$1.7, U$1.8
M2B: J7.14, U$1.11, U$1.12
M3A: J7.4, U$2.1, U$2.2
M3B: J7.13, U$2.5, U$2.6
M4A: J7.5, U$2.7, U$2.8
M4B: J7.12, U$2.11, U$2.12
unnamed: J5.1, J5.16, U1.48, U$3.1
unnamed: C10.2, R2.1, U1.29
unnamed: C7.2, R3.1, U1.30
unnamed: J1.2, R3.2
unnamed: J1.3, R1.1, R2.2
unnamed: C12.2, TP11.TP, U1.22, Y1.1
unnamed: Q1.3, R1.2, TP10.TP
unnamed: C11.2, TP12.TP, U1.23, Y1.2
unnamed: Q1.1, R4.2
unnamed: R5.1, U1.21
unnamed: C20.1, R6.1, R7.2, TP8.TP, U4.11
unnamed: U1.98, U5.11
unnamed: U1.99, U5.12
unnamed: C21.1, R8.1, R9.2, U3.11
unnamed: C23.2, U5.4
unnamed: C23.1, U5.5
unnamed: C22.1, U5.1
unnamed: C22.2, U5.3
unnamed: C26.2, U5.6
unnamed: C25.1, U5.2
unnamed: R19.2, U1.60
NTRST: J4.2, TP15.TP, U1.4
P2_9: R4.1, TP9.TP, U1.64
PWM1: U1.69, U$1.23
PWM2: U1.68, U$1.15
PWM3: U1.67, U$2.23
PWM4: U1.66, U$2.15
RST: J4.8, R18.1, TP20.TP, U1.17
RTCK: J4.6, TP19.TP, U1.100
RXD1: U1.74, U5.9
SER1_RX: J2.2, U5.13
SER1_TX: J2.3, U5.14
SER2_RX: J2.1, U5.8
SER2_TX: J2.6, U5.7
STBY: U1.87, U$1.19, U$2.19
TCK: J4.5, TP18.TP, U1.5
TDI: J4.3, TP16.TP, U1.2
TDO: TP21.TP, U1.1
TMS: J4.4, TP17.TP, U1.3
TXD1: U1.75, U5.10
T_RTCK: J5.6, U1.57, U$3.6
T_SRST: J5.8, U1.56, U$3.8
T_SWDCLK: J5.5, U1.62, U$3.5
T_SWDIO: J5.4, R19.1, U1.61, U$3.4
T_SWO: J5.7, U1.49, U$3.7
T_TDI: J5.3, U1.58, U$3.3
T_TRST: J5.2, U1.63, U$3.2
VCC: C15.1, C18.1, C24.1, J1.1, R5.2, TP14.TP, U2.3, U3.3, U4.3, U5.16
VDD: C1.2, C2.2, C3.2, C4.2, C5.2, C6.2, C8.2, C9.2, C13.1, C14.2, C17.2, C28.2, C30.1, C32.2, C34.1, J4.1, J4.16, Q1.2, R18.2, TP13.TP, U1.10, U1.12, U1.19, U1.28, U1.42, U1.54, U1.71, U1.84, U1.96, U2.2, U2.TER, U3.5, U4.5, U$1.20, U$2.20

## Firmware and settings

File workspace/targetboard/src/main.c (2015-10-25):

/*
 * main.c
 *
 *  Created on: 20-Sep-2015
 *      Author: thorsten
 */

#include "board.h"
#define TICKRATE_HZ1 (6)       /* 10 ticks per second */
#include "motor.h"
void SysTick_Handler(void)
{

	//Board_LED_Toggle(3);
	//Board_LED_Toggle(1);
	//Board_LED_Toggle(2);
}


#include "app_usbd_cfg.h"
#include "cdc_uart.h"

/*****************************************************************************
 * Private types/enumerations/variables
 ****************************************************************************/

/*****************************************************************************
 * Public types/enumerations/variables
 ****************************************************************************/

static USBD_HANDLE_T g_hUsb;

extern const  USBD_HW_API_T hw_api;
extern const  USBD_CORE_API_T core_api;
extern const  USBD_CDC_API_T cdc_api;
/* Since this example only uses CDC class link functions for that clas only */
static const  USBD_API_T g_usbApi = {
		&hw_api,
		&core_api,
		0,
		0,
		0,
		&cdc_api,
		0,
		0x02221101,
};

const  USBD_API_T *g_pUsbApi = &g_usbApi;

/*****************************************************************************
 * Private functions
 ****************************************************************************/

/* Initialize pin and clocks for USB0/USB1 port */
static void usb_pin_clk_init(void)
{
	/* enable USB PLL and clocks */
	Chip_USB_Init();
	/* enable USB 1 port on the board */
	Board_USBD_Init(1);
}

/*****************************************************************************
 * Public functions
 ****************************************************************************/

/**
 * @brief	Handle interrupt from USB0
 * @return	Nothing
 */
void USB_IRQHandler(void)
{
	USBD_API->hw->ISR(g_hUsb);
}

uint32_t values[500]={0};
uint32_t values_low[500]={0};
uint32_t values_high[500]={0};
uint32_t valuepos=0;
uint32_t valuelowpos=0;
uint32_t valuehighpos=0;
uint32_t lowMin=0xFFFFFFFF;
uint32_t lowMax=0;
uint32_t highMin=0xFFFFFFFF;
uint32_t highMax=0;
uint32_t start=0;
uint32_t received=0;
uint32_t receivedNow=0;
uint32_t receivedValues[32];
uint32_t receivedValuesPos=0;
uint32_t bitsrecevied[500]={0};
uint32_t bitsreceviedPos=0;
uint32_t bitCount;
void EINT3_IRQHandler(void)
{
	uint32_t curValue=0;

	if(Chip_GPIOINT_IsIntPending(LPC_GPIOINT, 0))
	{

		int falling=(Chip_GPIOINT_GetStatusFalling(LPC_GPIOINT,0) & (1<<24));
		int rising=(Chip_GPIOINT_GetStatusRising(LPC_GPIOINT,0) & (1<<24));
		if(  falling &&
				rising
		)
		{

		}else {
			curValue=Chip_TIMER_ReadCount(LPC_TIMER0);
			Chip_TIMER_Reset(LPC_TIMER0);
			Chip_TIMER_Enable(LPC_TIMER0);
			if(falling)
			{

				Chip_GPIOINT_SetIntRising(LPC_GPIOINT,GPIOINT_PORT0,1<<24);

				if(start==1)
				{
					received <<=1;
					bitCount++;
					if(curValue > 14722)
					{
						received|=1;
					}
					values_low[valuelowpos]=curValue;
					valuelowpos++;
					if(valuelowpos>=500)
						valuelowpos=499;
				}

			}else if(rising)
			{
				if(start==1)
				{
					received <<=1;
					bitCount++;
					if(curValue > 14722)
					{
						received|=1;
					}
					values_low[valuelowpos]=curValue;
					valuelowpos++;
					if(valuelowpos>=500)
						valuelowpos=499;
				}

				// LG remoteif(curValue>208468 && curValue<900000)
				if(curValue>60433 && curValue<900000)
				{
					received=0;
					start=1;
					bitCount=0;

			    // 	Board_LED_Set(1, 1);
				}



			}
			if(  bitCount==33 || bitCount==35)
			{
				receivedNow=received;
				receivedValues[receivedValuesPos]=received;
				if(receivedValuesPos<31)
					receivedValuesPos++;

			}

			if(start==1)
			{
				values[valuepos]=curValue;
								if(valuepos<499)
									valuepos++;

			}
		}


		Chip_GPIOINT_ClearIntStatus(LPC_GPIOINT, 0,1<<24);


	}
	NVIC_ClearPendingIRQ(EINT3_IRQn);

}

/* Find the address of interface descriptor for given class type. */
USB_INTERFACE_DESCRIPTOR *find_IntfDesc(const uint8_t *pDesc, uint32_t intfClass, int occ)
{
	USB_COMMON_DESCRIPTOR *pD;
	USB_INTERFACE_DESCRIPTOR *pIntfDesc = 0;
	uint32_t next_desc_adr;

	pD = (USB_COMMON_DESCRIPTOR *) pDesc;
	next_desc_adr = (uint32_t) pDesc;

	while (pD->bLength) {
		/* is it interface descriptor */
		if (pD->bDescriptorType == USB_INTERFACE_DESCRIPTOR_TYPE) {

			pIntfDesc = (USB_INTERFACE_DESCRIPTOR *) pD;
			/* did we find the right interface descriptor */
			if (pIntfDesc->bInterfaceClass == intfClass ) {
				if( occ==0)
					break;
				else
					occ--;
			}
		}
		pIntfDesc = 0;
		next_desc_adr = (uint32_t) pD + pD->bLength;
		pD = (USB_COMMON_DESCRIPTOR *) next_desc_adr;
	}

	return pIntfDesc;
}


int main(void)
{

	USBD_API_INIT_PARAM_T usb_param;
	USB_CORE_DESCS_T desc;
	ErrorCode_t ret = LPC_OK;
	Board_Init();
	Board_SetupClocking();
	Chip_USB_Init();
	Motor_Init();

	SystemCoreClockUpdate();

	/* Enable and setup SysTick Timer at a periodic rate */
	SysTick_Config(SystemCoreClock / TICKRATE_HZ1);

	/* enable clocks and pinmux */
	usb_pin_clk_init();



	/* initialize call back structures */
	memset((void *) &usb_param, 0, sizeof(USBD_API_INIT_PARAM_T));
	usb_param.usb_reg_base = LPC_USB_BASE + 0x200;
	usb_param.max_num_ep =16;
	usb_param.mem_base = USB_STACK_MEM_BASE;
	usb_param.mem_size = USB_STACK_MEM_SIZE;

	/* Set the USB descriptors */
	desc.device_desc = (uint8_t *) &USB_DeviceDescriptor[0];
	desc.string_desc = (uint8_t *) &USB_StringDescriptor[0];
	/* Note, to pass USBCV test full-speed only devices should have both
	        	   descriptor arrays point to same location and device_qualifier set to 0.
	 */
	desc.high_speed_desc = (uint8_t *) &USB_FsConfigDescriptor[0];
	desc.full_speed_desc = (uint8_t *) &USB_FsConfigDescriptor[0];
	desc.device_qualifier = 0;




	Chip_GPIO_SetPinDIROutput(LPC_GPIO,2,9);
	Chip_GPIO_SetPinOutLow(LPC_GPIO,2,9);//Pull up usb port as a slave.
	Chip_GPIO_SetPinDIROutput(LPC_GPIO,1,18);



	// Stuff for IR, enable Pin I/O Interrupt
	Chip_GPIOINT_Init(LPC_GPIOINT);
	NVIC_SetPriority(EINT3_IRQn, 1);
	Chip_GPIOINT_SetIntFalling(LPC_GPIOINT,GPIOINT_PORT0,1<<24);
	//Chip_GPIOINT_SetIntRising(LPC_GPIOINT,GPIOINT_PORT0,1<<24);
	Chip_GPIOINT_ClearIntStatus(LPC_GPIOINT, 0,1<<24);
	NVIC_ClearPendingIRQ(EINT3_IRQn);
	 NVIC_EnableIRQ(EINT3_IRQn);
	 Chip_TIMER_Init(LPC_TIMER0);

	 for(int i=0;i<500;i++)
	 {
	 values[i]=0;
	  values_low[i]=0;
	 values_high[i]=0;
	 }
	 start=0;

	/* USB Initialization */
	ret = USBD_API->hw->Init(&g_hUsb, &desc, &usb_param);
	if (ret == LPC_OK) {


		/* Init UCOM - USB to UART bridge interface */
		ret = UCOM_init(g_hUsb, &desc, &usb_param);
		if (ret == LPC_OK) {
			/* Make sure USB and UART IRQ priorities are same for this example */
			NVIC_SetPriority(USB_IRQn, 1);
			/*  enable USB interrupts */
			NVIC_EnableIRQ(USB_IRQn);
			NVIC_EnableIRQ(UART0_IRQn);
			NVIC_EnableIRQ(UART2_IRQn);
			/* now connect */
			USBD_API->hw->Connect(g_hUsb, 1);
		}
	}
	Board_UARTPutSTR("ABC\n");
	uint8_t g_rxBuff[256];
	uint32_t prompt = 0, rdCnt = 0;


	//ESP into reset
	Chip_GPIO_SetPinState(	LPC_GPIO, 0 ,6 ,0);
	__enable_irq();
	int count=0;
	bitsreceviedPos=0;
	while (1) {

		switch(receivedNow)
		{
		case 0x418030E7:
		case 0x4300C39D:
			count=1000000;
			Board_LED_Set(0, 1);
			Motor_All(MOTOR_LEFT);
			break;
		case 1124123539:
		case 100713363:
			Motor_All(MOTOR_RIGHT);
			Board_LED_Set(1, 1);
			count=1000000;
			break;
		case 1124123545:
		case 100713369:
			Board_LED_Set(2, 1);
			count=1000000;
			break;
		}
		receivedNow=0;
		if(count>0)
		{
			count--;
		}else{
		//	Motor_All(MOTOR_STOP);
			Board_LED_Set(0, 0);
			Board_LED_Set(1, 0);
			Board_LED_Set(2, 0);
		}

	}
}

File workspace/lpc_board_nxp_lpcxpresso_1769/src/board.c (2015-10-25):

/*
 * @brief NXP LPC1769 LPCXpresso board file
 *
 * @note
 * Copyright(C) NXP Semiconductors, 2012
 * All rights reserved.
 *
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
 * @par
 * Permission to use, copy, modify, and distribute this software and its
 * documentation is hereby granted, under NXP Semiconductors' and its
 * licensor's relevant copyrights in the software, without fee, provided that it
 * is used in conjunction with NXP Semiconductors microcontrollers.  This
 * copyright, permission, and disclaimer notice must appear in all copies of
 * this code.
 */

#include "board.h"
#include "string.h"

#include "retarget.h"

/*****************************************************************************
 * Private types/enumerations/variables
 ****************************************************************************/
#define BUTTONS_BUTTON1_GPIO_PORT_NUM           2
#define BUTTONS_BUTTON1_GPIO_BIT_NUM            10
#define BUTTONS_BUTTON2_GPIO_PORT_NUM           0
#define BUTTONS_BUTTON2_GPIO_BIT_NUM            24


#define LED0_GPIO_PORT_NUM                      0
#define LED0_GPIO_BIT_NUM                       23
#define LED1_GPIO_PORT_NUM                      3
#define LED1_GPIO_BIT_NUM                       25
#define LED2_GPIO_PORT_NUM                      3
#define LED2_GPIO_BIT_NUM                       26

#define LED3_GPIO_PORT_NUM                      1
#define LED3_GPIO_BIT_NUM                       18  // IR LED

/*****************************************************************************
 * Public types/enumerations/variables
 ****************************************************************************/

/* System oscillator rate and RTC oscillator rate */
const uint32_t OscRateIn = 12000000;
const uint32_t RTCOscRateIn = 32768;

/*****************************************************************************
 * Private functions
 ****************************************************************************/

/* Initializes board LED(s) */
static void Board_LED_Init(void)
{
	/* Pin PIO0_22 is configured as GPIO pin during SystemInit */
	/* Set the PIO_22 as output */
	Chip_GPIO_WriteDirBit(LPC_GPIO, LED0_GPIO_PORT_NUM, LED0_GPIO_BIT_NUM, true);
	Chip_GPIO_WriteDirBit(LPC_GPIO, LED1_GPIO_PORT_NUM, LED1_GPIO_BIT_NUM, true);
	Chip_GPIO_WriteDirBit(LPC_GPIO, LED2_GPIO_PORT_NUM, LED2_GPIO_BIT_NUM, true);
	Chip_GPIO_WriteDirBit(LPC_GPIO, LED3_GPIO_PORT_NUM, LED3_GPIO_BIT_NUM, true);

}

/*****************************************************************************
 * Public functions
 ****************************************************************************/

/* Initialize UART pins */
void Board_UART_Init(LPC_USART_T *pUART)
{
	/* Pin Muxing has already been done during SystemInit */
}

/* Initialize debug output via UART for board */
void Board_Debug_Init(void)
{
#if defined(DEBUG_ENABLE)
	Board_UART_Init(DEBUG_UART);

	Chip_UART_Init(DEBUG_UART);
	Chip_UART_SetBaud(DEBUG_UART, 115200);
	Chip_UART_ConfigData(DEBUG_UART, UART_LCR_WLEN8 | UART_LCR_SBS_1BIT | UART_LCR_PARITY_DIS);

	/* Enable UART Transmit */
	Chip_UART_TXEnable(DEBUG_UART);
#endif
}

/* Sends a character on the UART */
void Board_UARTPutChar(char ch)
{
#if defined(DEBUG_ENABLE)
	while ((Chip_UART_ReadLineStatus(DEBUG_UART) & UART_LSR_THRE) == 0) {}
	Chip_UART_SendByte(DEBUG_UART, (uint8_t) ch);
#endif
}

/* Gets a character from the UART, returns EOF if no character is ready */
int Board_UARTGetChar(void)
{
#if defined(DEBUG_ENABLE)
	if (Chip_UART_ReadLineStatus(DEBUG_UART) & UART_LSR_RDR) {
		return (int) Chip_UART_ReadByte(DEBUG_UART);
	}
#endif
	return EOF;
}

/* Outputs a string on the debug UART */
void Board_UARTPutSTR(char *str)
{
#if defined(DEBUG_ENABLE)
	while (*str != '\0') {
		Board_UARTPutChar(*str++);
	}
#endif
}

/* Sets the state of a board LED to on or off */
void Board_LED_Set(uint8_t LEDNumber, bool On)
{
	/* There is only one LED */
	if (LEDNumber == 0) {
		Chip_GPIO_WritePortBit(LPC_GPIO, LED0_GPIO_PORT_NUM, LED0_GPIO_BIT_NUM, On);
	}
	if (LEDNumber == 1) {
		Chip_GPIO_WritePortBit(LPC_GPIO, LED1_GPIO_PORT_NUM, LED1_GPIO_BIT_NUM, On);
	}
	if (LEDNumber == 2) {
		Chip_GPIO_WritePortBit(LPC_GPIO, LED2_GPIO_PORT_NUM, LED2_GPIO_BIT_NUM, On);
	}
	if (LEDNumber == 3) {
		Chip_GPIO_WritePortBit(LPC_GPIO, LED3_GPIO_PORT_NUM, LED3_GPIO_BIT_NUM, On);
	}
}

/* Returns the current state of a board LED */
bool Board_LED_Test(uint8_t LEDNumber)
{
	bool state = false;

	if (LEDNumber == 0) {
		state = Chip_GPIO_ReadPortBit(LPC_GPIO, LED0_GPIO_PORT_NUM, LED0_GPIO_BIT_NUM);
	}
	if (LEDNumber == 1) {
		state = Chip_GPIO_ReadPortBit(LPC_GPIO, LED1_GPIO_PORT_NUM, LED1_GPIO_BIT_NUM);
	}
	if (LEDNumber == 2) {
		state = Chip_GPIO_ReadPortBit(LPC_GPIO, LED2_GPIO_PORT_NUM, LED2_GPIO_BIT_NUM);
	}

	if (LEDNumber == 3) {
		state = Chip_GPIO_ReadPortBit(LPC_GPIO, LED3_GPIO_PORT_NUM, LED3_GPIO_BIT_NUM);
	}

	return state;
}
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

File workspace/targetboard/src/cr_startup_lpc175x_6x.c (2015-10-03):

//*****************************************************************************
// LPC175x_6x Microcontroller Startup code for use with LPCXpresso IDE
//
// Version : 140114
//*****************************************************************************
//
// Copyright(C) NXP Semiconductors, 2014
// All rights reserved.
//
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
// Permission to use, copy, modify, and distribute this software and its
// documentation is hereby granted, under NXP Semiconductors' and its
// licensor's relevant copyrights in the software, without fee, provided that it
// is used in conjunction with NXP Semiconductors microcontrollers.  This
// copyright, permission, and disclaimer notice must appear in all copies of
// this code.
//*****************************************************************************

#if defined (__cplusplus)
#ifdef __REDLIB__
#error Redlib does not support C++
#else
//*****************************************************************************
//
// The entry point for the C++ library startup
//
//*****************************************************************************
extern "C" {
    extern void __libc_init_array(void);
}
#endif
#endif

#define WEAK __attribute__ ((weak))
#define ALIAS(f) __attribute__ ((weak, alias (#f)))

//*****************************************************************************
#if defined (__cplusplus)
extern "C" {
#endif

//*****************************************************************************
#if defined (__USE_CMSIS) || defined (__USE_LPCOPEN)
// Declaration of external SystemInit function
extern void SystemInit(void);
#endif

//*****************************************************************************
//
// Forward declaration of the default handlers. These are aliased.
// When the application defines a handler (with the same name), this will
// automatically take precedence over these weak definitions
//
//*****************************************************************************
     void ResetISR(void);
WEAK void NMI_Handler(void);
WEAK void HardFault_Handler(void);
WEAK void MemManage_Handler(void);
WEAK void BusFault_Handler(void);
WEAK void UsageFault_Handler(void);
WEAK void SVC_Handler(void);
WEAK void DebugMon_Handler(void);
WEAK void PendSV_Handler(void);
WEAK void SysTick_Handler(void);
WEAK void IntDefaultHandler(void);

//*****************************************************************************
//
// Forward declaration of the specific IRQ handlers. These are aliased
// to the IntDefaultHandler, which is a 'forever' loop. When the application
// defines a handler (with the same name), this will automatically take
// precedence over these weak definitions
//
//*****************************************************************************
void WDT_IRQHandler(void) ALIAS(IntDefaultHandler);
void TIMER0_IRQHandler(void) ALIAS(IntDefaultHandler);
void TIMER1_IRQHandler(void) ALIAS(IntDefaultHandler);
void TIMER2_IRQHandler(void) ALIAS(IntDefaultHandler);
void TIMER3_IRQHandler(void) ALIAS(IntDefaultHandler);
void UART0_IRQHandler(void) ALIAS(IntDefaultHandler);
void UART1_IRQHandler(void) ALIAS(IntDefaultHandler);
void UART2_IRQHandler(void) ALIAS(IntDefaultHandler);
void UART3_IRQHandler(void) ALIAS(IntDefaultHandler);
void PWM1_IRQHandler(void) ALIAS(IntDefaultHandler);
void I2C0_IRQHandler(void) ALIAS(IntDefaultHandler);
void I2C1_IRQHandler(void) ALIAS(IntDefaultHandler);
void I2C2_IRQHandler(void) ALIAS(IntDefaultHandler);
void SPI_IRQHandler(void) ALIAS(IntDefaultHandler);
void SSP0_IRQHandler(void) ALIAS(IntDefaultHandler);
void SSP1_IRQHandler(void) ALIAS(IntDefaultHandler);
void PLL0_IRQHandler(void) ALIAS(IntDefaultHandler);
void RTC_IRQHandler(void) ALIAS(IntDefaultHandler);
void EINT0_IRQHandler(void) ALIAS(IntDefaultHandler);
void EINT1_IRQHandler(void) ALIAS(IntDefaultHandler);
void EINT2_IRQHandler(void) ALIAS(IntDefaultHandler);
void EINT3_IRQHandler(void) ALIAS(IntDefaultHandler);
void ADC_IRQHandler(void) ALIAS(IntDefaultHandler);
void BOD_IRQHandler(void) ALIAS(IntDefaultHandler);
void USB_IRQHandler(void) ALIAS(IntDefaultHandler);
void CAN_IRQHandler(void) ALIAS(IntDefaultHandler);
void DMA_IRQHandler(void) ALIAS(IntDefaultHandler);
void I2S_IRQHandler(void) ALIAS(IntDefaultHandler);
#if defined (__USE_LPCOPEN)
void ETH_IRQHandler(void) ALIAS(IntDefaultHandler);
#else
void ENET_IRQHandler(void) ALIAS(IntDefaultHandler);
#endif
void RIT_IRQHandler(void) ALIAS(IntDefaultHandler);
void MCPWM_IRQHandler(void) ALIAS(IntDefaultHandler);
void QEI_IRQHandler(void) ALIAS(IntDefaultHandler);
void PLL1_IRQHandler(void) ALIAS(IntDefaultHandler);
void USBActivity_IRQHandler(void) ALIAS(IntDefaultHandler);
void CANActivity_IRQHandler(void) ALIAS(IntDefaultHandler);

//*****************************************************************************
//
// The entry point for the application.
// __main() is the entry point for Redlib based applications
// main() is the entry point for Newlib based applications
//
//*****************************************************************************
#if defined (__REDLIB__)
extern void __main(void);
#endif
extern int main(void);
//*****************************************************************************
//
// External declaration for the pointer to the stack top from the Linker Script
//
//*****************************************************************************
extern void _vStackTop(void);
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

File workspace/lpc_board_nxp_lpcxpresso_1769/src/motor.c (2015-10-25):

/*
 * motor.c
 *
 *  Created on: 25-Oct-2015
 *      Author: thorsten
 */
#include "motor.h"
#include "board.h"
typedef struct {
   int port;
   int bit;

} tPin;
typedef struct
{
	tPin pwm;
	tPin a;
	tPin b;
} tMotorDef;

#define MOTOR_STBY_PORT_NUM 1
#define MOTOR_STBY_BIT_NUM 4

#define NUM_MOTOR 4
const tMotorDef MOTOR[NUM_MOTOR]=
{
		{
		{2,4},
		{1,9},
		{1,8},
		},

		{
				{2,5},
				{1,1},
				{1,0},
		},

		{
				{1,21},
				{0,9},
				{1,10},
		},

		{
				{1,23},
				{1,14},
				{0,8},
		},
};

void Motor_Init(void)
{
	Chip_GPIO_WriteDirBit(LPC_GPIO, MOTOR_STBY_PORT_NUM, MOTOR_STBY_BIT_NUM, true);

	int i;
	for(int i=0;i<NUM_MOTOR;i++)
	{
		Chip_GPIO_WriteDirBit(LPC_GPIO, MOTOR[i].pwm.port, MOTOR[i].pwm.bit, true);
		Chip_GPIO_WriteDirBit(LPC_GPIO, MOTOR[i].a.port, MOTOR[i].a.bit, true);
		Chip_GPIO_WriteDirBit(LPC_GPIO, MOTOR[i].b.port, MOTOR[i].b.bit, true);
	}

	Chip_GPIO_WritePortBit(LPC_GPIO, MOTOR_STBY_PORT_NUM, MOTOR_STBY_BIT_NUM, true);
}


void Moror_Do(int i, eDirection dir)
{
	if(i<NUM_MOTOR)
	{
		if(dir==MOTOR_OFF)
		{
			Chip_GPIO_WritePortBit(LPC_GPIO, MOTOR[i].pwm.port, MOTOR[i].pwm.bit, false);
		}else{
			Chip_GPIO_WritePortBit(LPC_GPIO, MOTOR[i].pwm.port, MOTOR[i].pwm.bit, true);
		}
		switch(dir)
		{
		case MOTOR_STOP:
			Chip_GPIO_WritePortBit(LPC_GPIO, MOTOR[i].a.port, MOTOR[i].a.bit, false);
			Chip_GPIO_WritePortBit(LPC_GPIO, MOTOR[i].b.port, MOTOR[i].b.bit, false);
		break;
		case MOTOR_LEFT:
			Chip_GPIO_WritePortBit(LPC_GPIO, MOTOR[i].a.port, MOTOR[i].a.bit, false);
			Chip_GPIO_WritePortBit(LPC_GPIO, MOTOR[i].b.port, MOTOR[i].b.bit, true);
		break;
		case MOTOR_RIGHT:
			Chip_GPIO_WritePortBit(LPC_GPIO, MOTOR[i].a.port, MOTOR[i].a.bit, true);
			Chip_GPIO_WritePortBit(LPC_GPIO, MOTOR[i].b.port, MOTOR[i].b.bit, false);
		break;
		case MOTOR_OFF:
			Chip_GPIO_WritePortBit(LPC_GPIO, MOTOR[i].a.port, MOTOR[i].a.bit, true);
			Chip_GPIO_WritePortBit(LPC_GPIO, MOTOR[i].b.port, MOTOR[i].b.bit, true);
			break;
		}
	}
}
void Motor_All(eDirection dir)
{
	int i;
	for(int i=0;i<NUM_MOTOR;i++)
	{
		Moror_Do(i,dir);
	}

}

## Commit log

2015-01-26 Toggle one LED if something is there on COM3
2015-02-15 Move serial ports to be ACM devices
2015-07-25 Add ground for the linux driver
2015-08-09 Add eagle files
    [targetboard.brd, targetboard.job.brd, targetboard.sch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]
2015-08-22 Update of board
    [targetboard.brd, targetboard.sch]
2015-08-22 Add README.md
    [targetboard.brd, targetboard.sch]
2015-09-20 Fix Board revision, CAN VCC and VSS mixed up
    [targetboard.brd, targetboard.sch]
2015-09-20 Board V1 as it was produced
    [targetboard_v1.brd, targetboard_v1.sch]
2015-09-20 Add openocd configuration to debug with RPI - not RPi2 needs small differences in the configuration
    [my-raspberrypi-native.cfg]
2015-10-25 Configure pin for UART0
2015-10-25 Add motor control
    [targetboard_v1.sch]

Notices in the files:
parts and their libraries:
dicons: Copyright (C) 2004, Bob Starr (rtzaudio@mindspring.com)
